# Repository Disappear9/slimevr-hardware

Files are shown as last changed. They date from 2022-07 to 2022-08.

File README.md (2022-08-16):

# SlimeVR硬件（D9MOD）  
## 设计目标：  
1.IMU使用 GY-91模块。  
2.去除充电电路，使用集中供电     
3.去除USB-TTL芯片，在第一次下载后就用不着了。  
4.预留第二IMU端口，接口使用RJ11。  
5. 使用 ESP32-WROOM-32E 作为MCU

## 
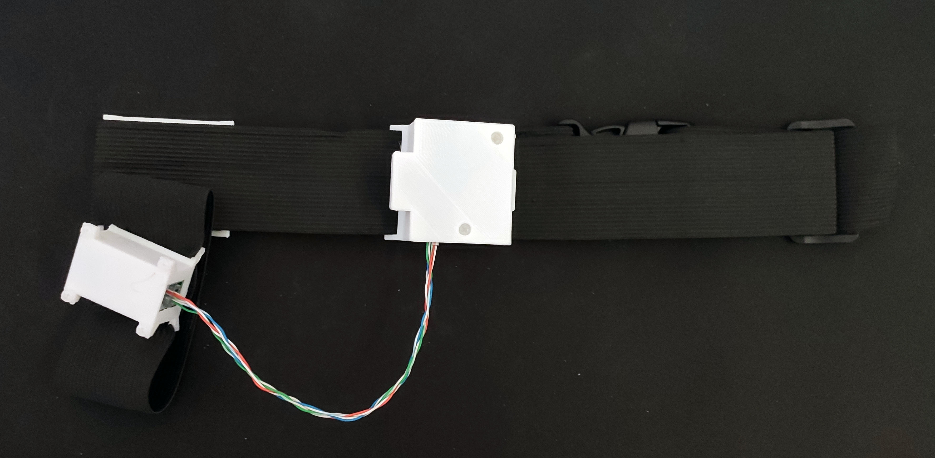
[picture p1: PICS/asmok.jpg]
ASMOK


## 更新日志
1.使用XC6210替换AMS1117  
2.对信号线重新layout  
3.拼板设计，打样后用钢锯/台锯沿孔洞切割  

## 其他
1.使用EDA软件为EASYEDA（立创EDA）  
2.文件 -> 打开 选择json文件即可导入  

### 固件  
https://github.com/Disappear9/SlimeVR-Tracker-ESP  
### 模型&组装说明  
[模型](/Model/README.MD)  
[组装说明](/Model/ASM.MD)  

# 项目进度  
- [x] 初始版本设计
- [x] 打样
- [x] 验证Core板运行状态
- [x] 验证AUX板运行状态
- [x] Core板外壳设计
- [x] AUX板外壳设计
- [x] 外壳打印验证
- [x] 绑带设计
- [x] 总装测试

# TODO  
1.腰部连线臃肿，需要设计PDU  
2.手柄干扰磁力计，下代更换IMU  

# LICENSE
CC BY-NC-SA 3.0
署名-非商业性使用-相同方式共享 3.0

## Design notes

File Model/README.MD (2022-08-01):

## 说明
PCB-REF文件夹中为板子+模块组合后模型，用于参考绘制外壳。  
CASE文件夹中为外壳设计文件。  
外壳同样分为两部分，Core与AUX。    

## 效果图
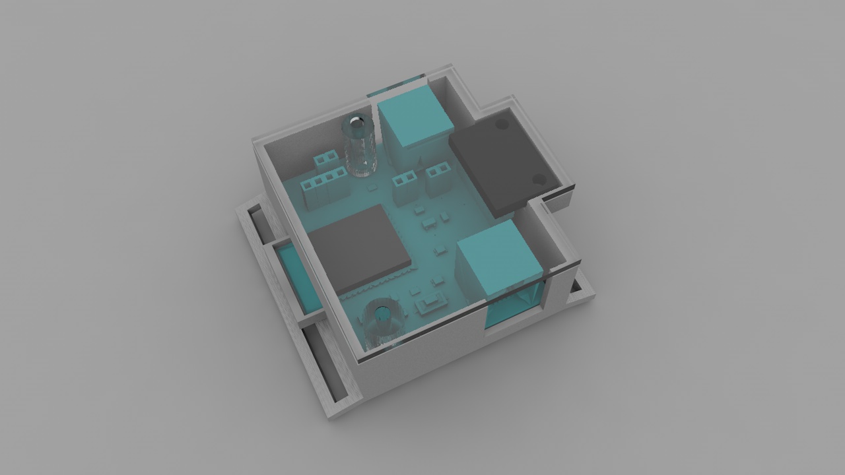
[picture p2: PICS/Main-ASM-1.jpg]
Main1

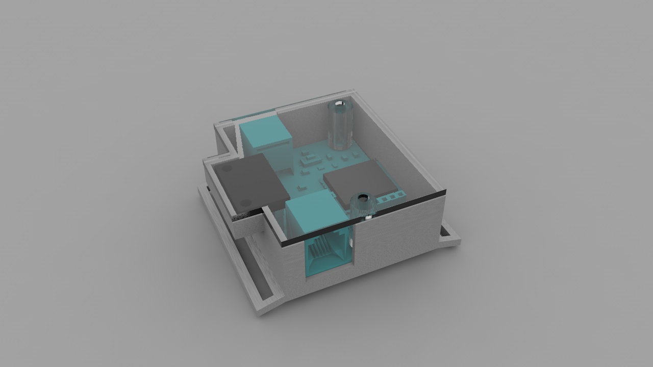
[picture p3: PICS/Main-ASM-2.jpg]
Main2

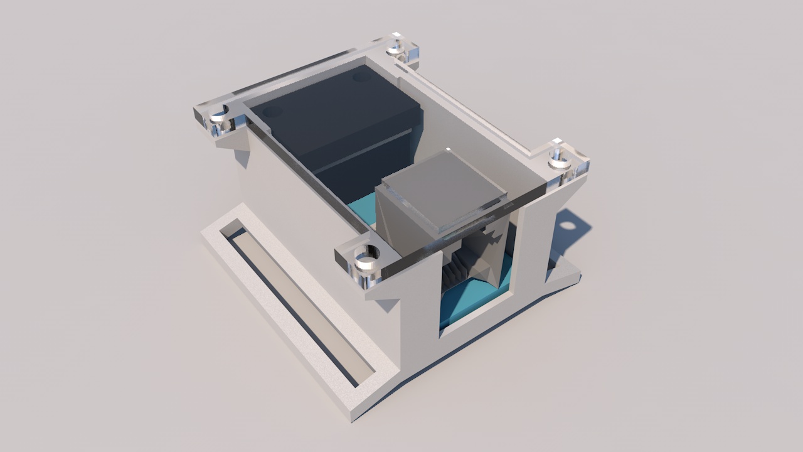
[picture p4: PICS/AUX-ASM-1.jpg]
AUX1

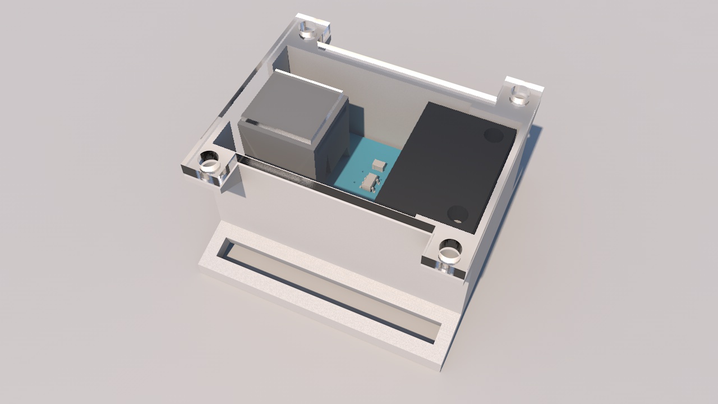
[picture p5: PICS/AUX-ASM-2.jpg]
AUX2


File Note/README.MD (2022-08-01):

DOC:  
https://docs.espressif.com/projects/esp-idf/zh_CN/latest/esp32/hw-reference/index.html  
https://docs.espressif.com/projects/esp-idf/zh_CN/latest/esp32/hw-reference/esp32/get-started-devkitc.html  

PDF:  
https://www.espressif.com/sites/default/files/documentation/esp32-wroom-32e_esp32-wroom-32ue_datasheet_cn.pdf  
https://www.nxp.com/docs/en/application-note/AN4247.pdf  

PICS:


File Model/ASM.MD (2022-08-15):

## 装配说明
### 材料
#### Main
M3 * 20mm 尼龙螺丝 X2  
M3 尼龙螺母 X2
#### AUX
M3 * 5mm 尼龙螺丝 X2  
#### 绑带
50mm松紧带（根据胸围、腰围、腿直径自行计算长度，缠一圈）  
50mm插扣 + 50mm人字扣 X6  

## 佩戴位置  
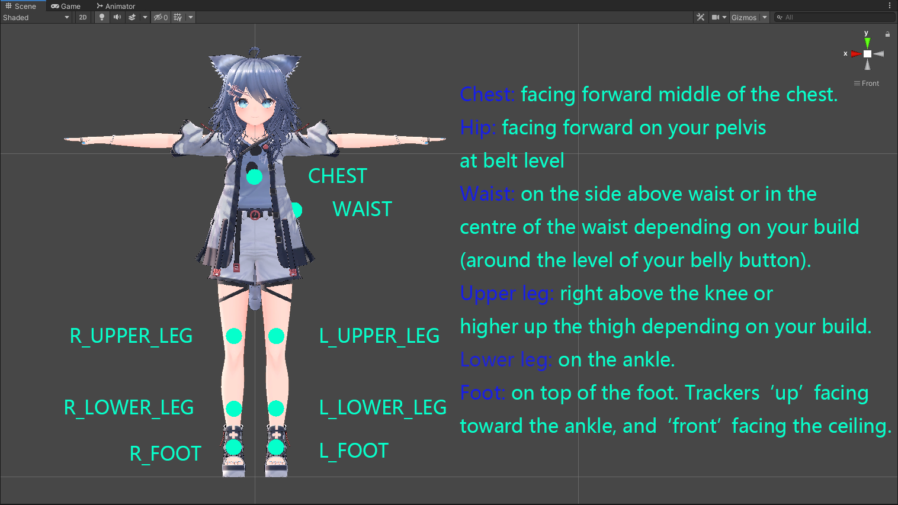
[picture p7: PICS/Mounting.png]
佩戴位置

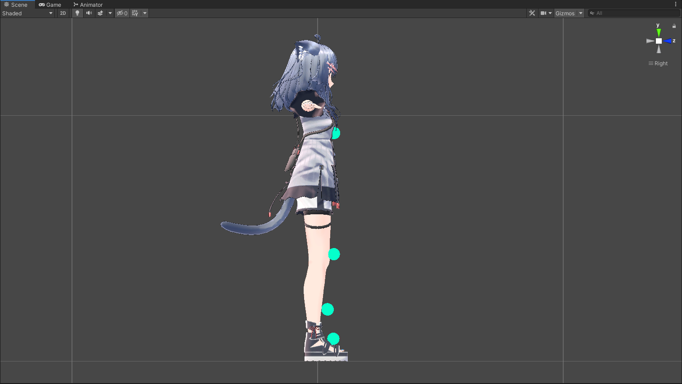
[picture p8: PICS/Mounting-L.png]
佩戴位置L

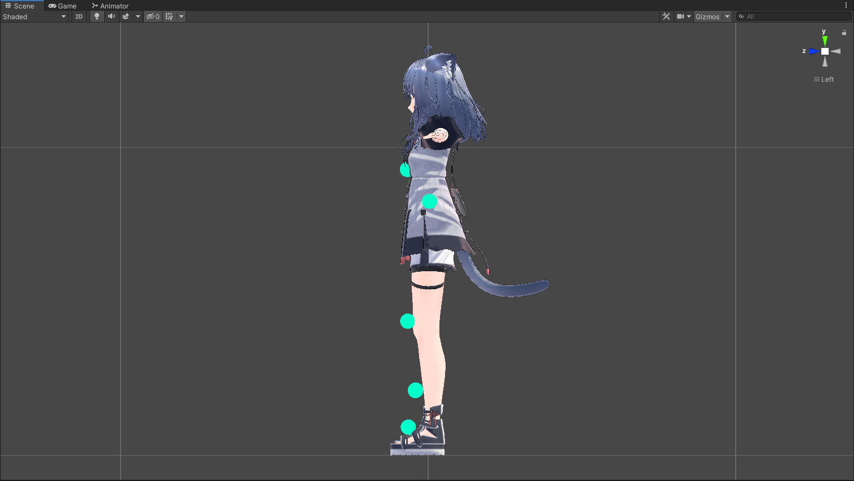
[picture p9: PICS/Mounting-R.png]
佩戴位置R


## 佩戴接线  
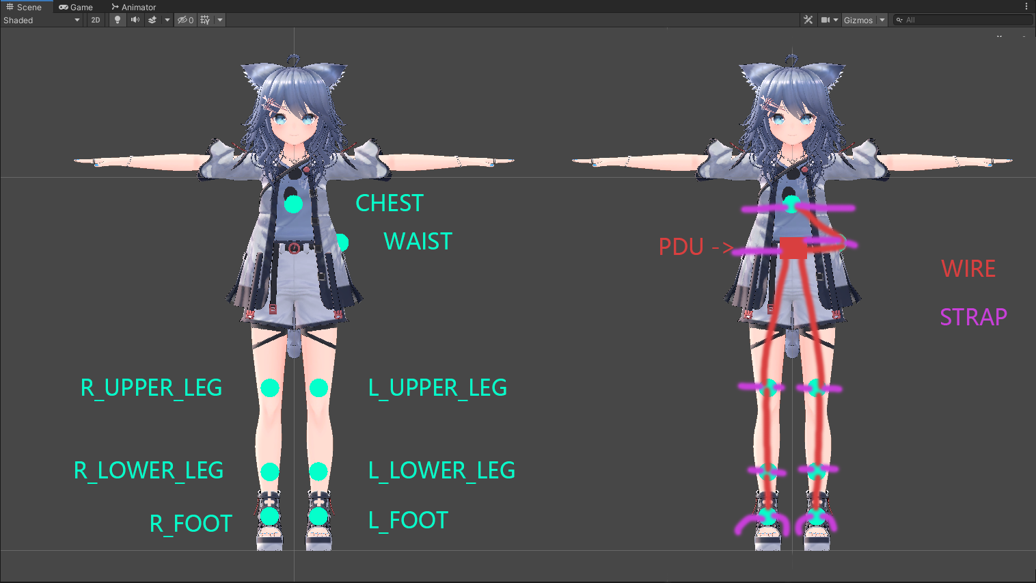
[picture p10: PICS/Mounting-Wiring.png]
佩戴接线


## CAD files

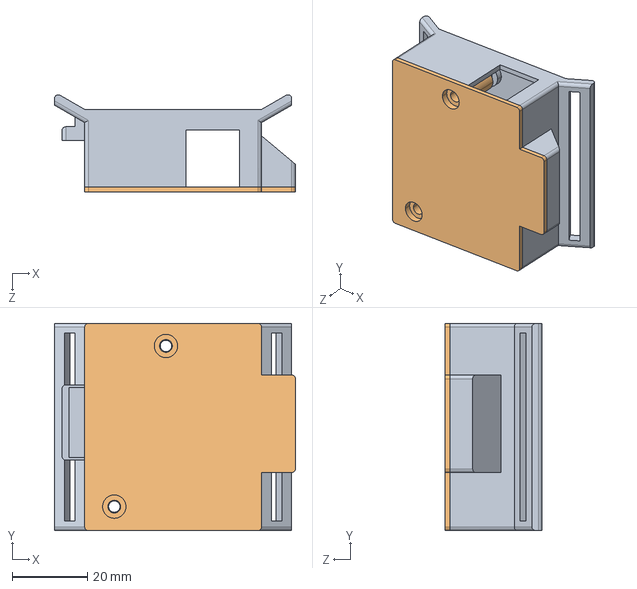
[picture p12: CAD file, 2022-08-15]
Model/CASE/Main装配体.STEP
64.0 x 55.0 x 25.9 mm
Main-Working
Cover

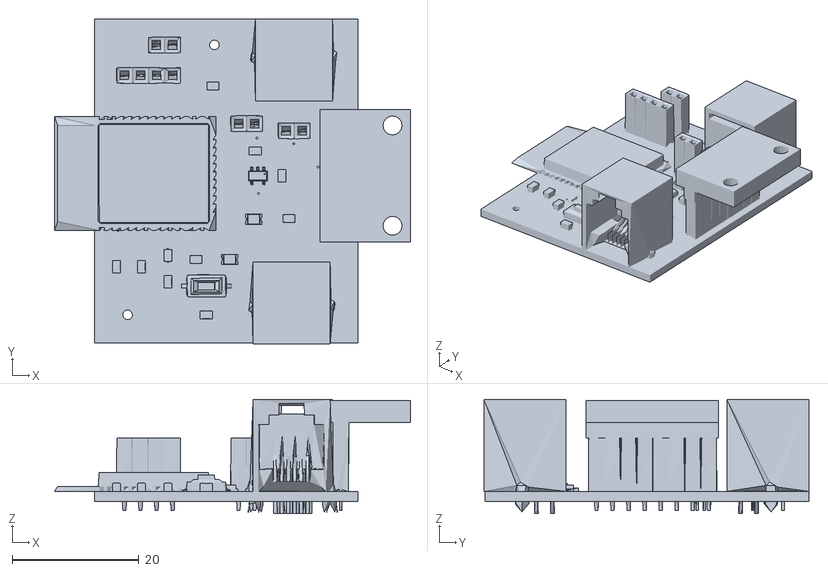
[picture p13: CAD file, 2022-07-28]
Model/PCB-REF/PCB_slime-vr_Main.stl
56.3 x 51.4 x 18.0

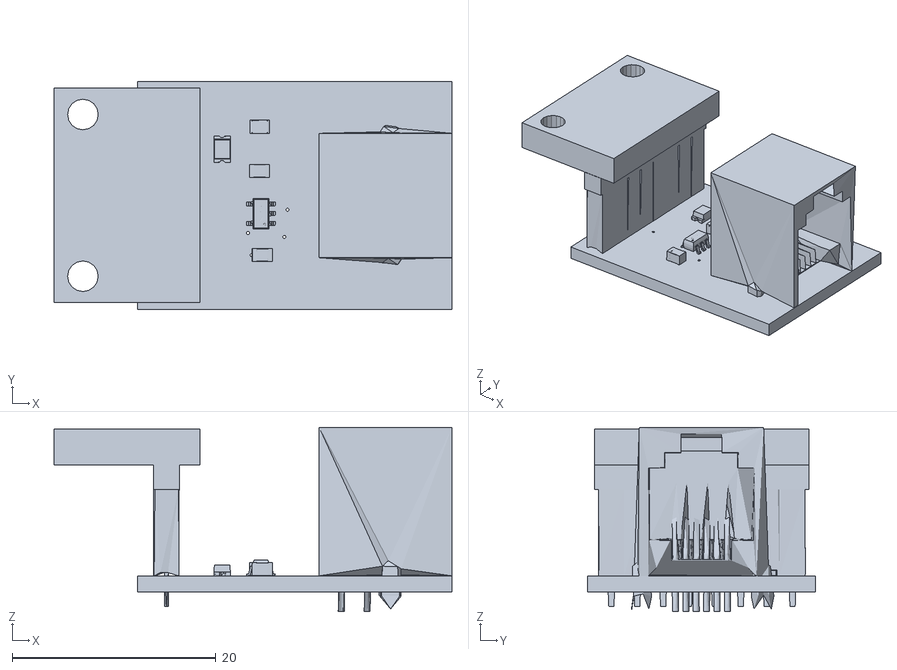
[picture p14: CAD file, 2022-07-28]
Model/PCB-REF/PCB_slime-vr_AUX.stl
39.0 x 22.4 x 18.0

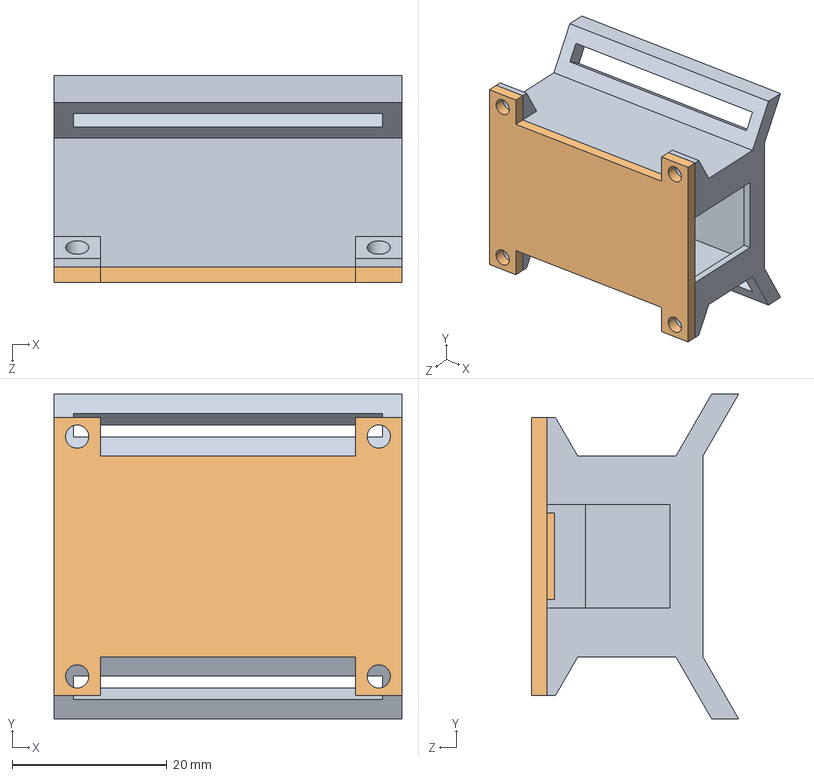
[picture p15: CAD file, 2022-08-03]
Model/CASE/AUX装配体.STEP
45.0 x 42.0 x 26.8 mm
3D_PCB_slime-vr_AUX
AUX-Cover

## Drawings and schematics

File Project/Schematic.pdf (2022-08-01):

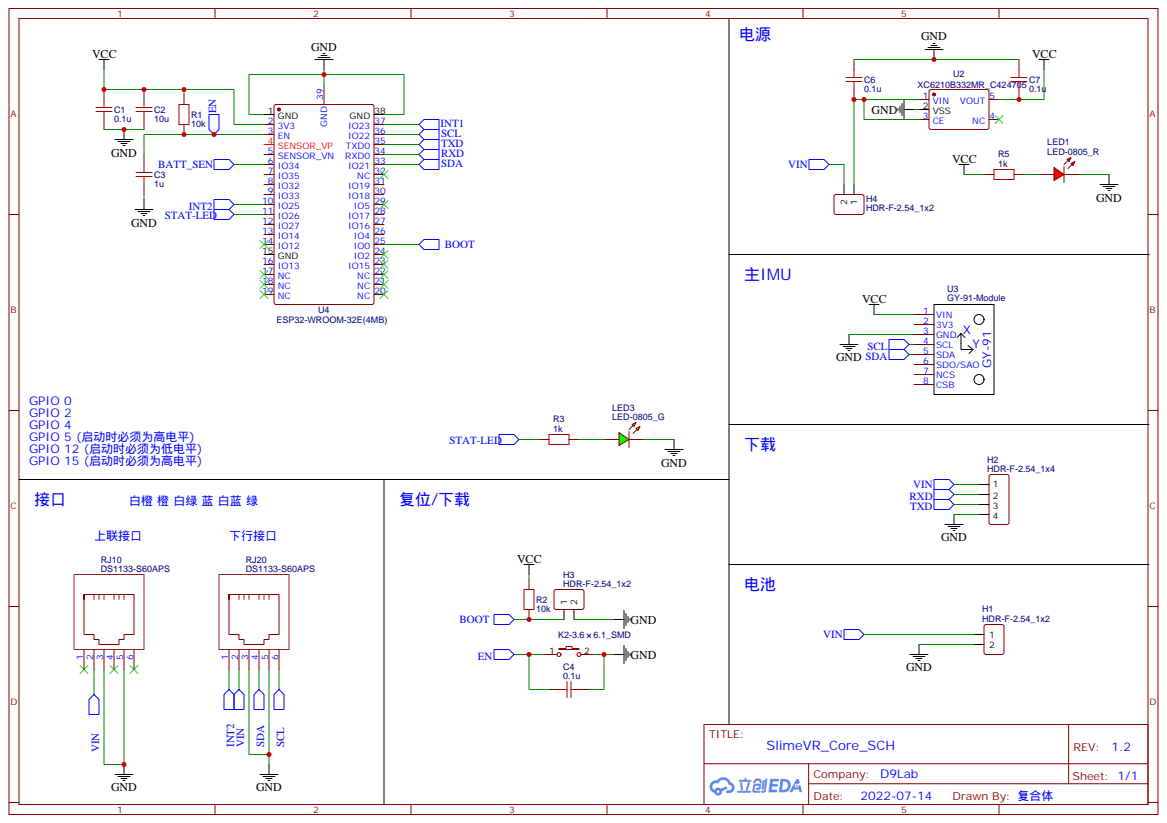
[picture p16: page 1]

电源

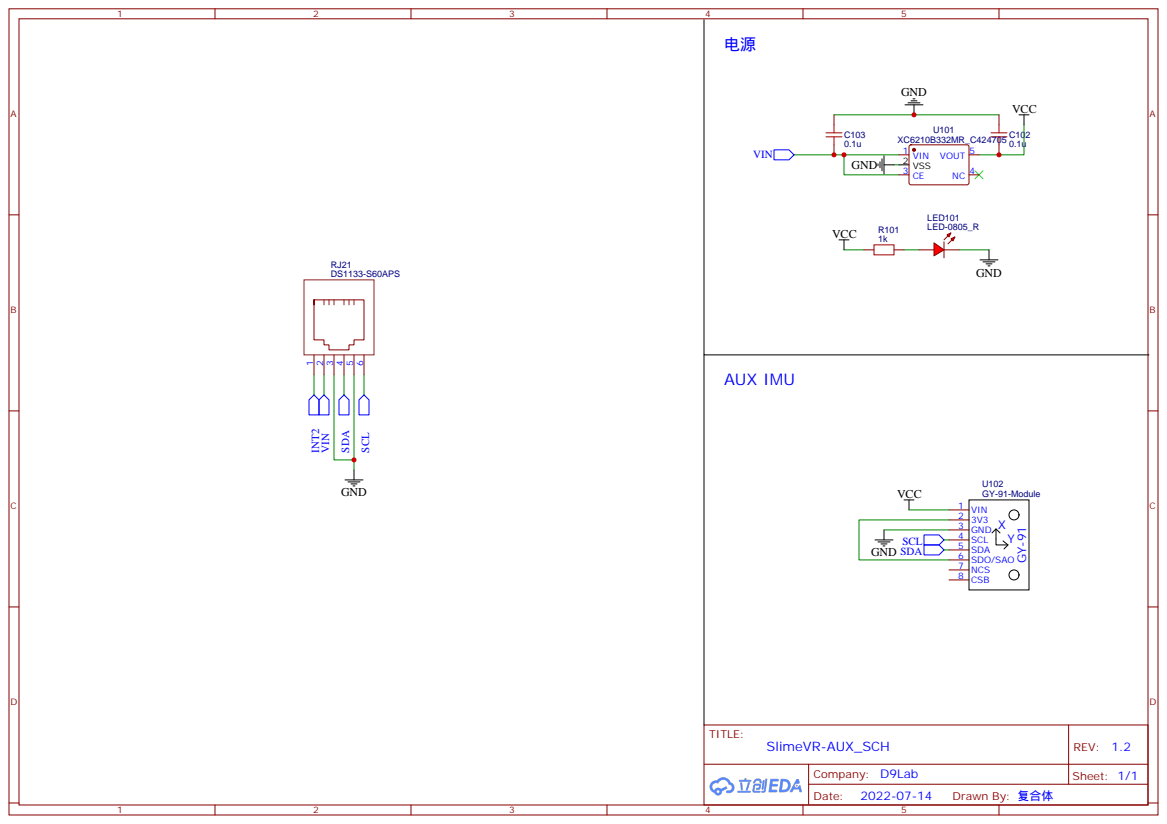
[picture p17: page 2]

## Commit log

2022-08-01 add case stl(wip), sort file.
    [Main-Cover.STL, Main.STL, PCB_slime-vr_AUX.stl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]
2022-08-01 Add AUX Case(wip)
    [AUX2-Cover.STL, AUX2.STL]
